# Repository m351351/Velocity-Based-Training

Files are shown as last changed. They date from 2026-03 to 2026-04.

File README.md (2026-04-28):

# Velocity-Based Training (VBT) - Device

[Suomeksi](README.md) | [In English](README_eng.md)

---

Tämä projekti on osa Oulun ammattikorkeakoulun tieto- ja viestintätekniikan toisen vuoden kevään elektroniikan sovellusprojekti-kurssia (2026). Projektin kesto on 7 viikkoa.

## Sisällysluettelo
* [Yleiskuvaus](#yleiskuvaus)
* [Laitteisto ja komponentit](#laitteisto-ja-komponentit)
* [Ohjelmisto ja teknologiat](#ohjelmisto-ja-teknologiat)
* [Toiminnallisuus](#toiminnallisuus)
* [Projektin hallinta](#projektin-hallinta)
* [Kuvat](#kuvat)

---

## Yleiskuvaus
Projektin tavoitteena on suunnitella ja toteuttaa Velocity-Based Training (VBT) -laite. Laite on tarkoitettu painonnostoon, jossa se mittaa levytangon liikettä ja antaa nostajalle reaaliaikaista palautetta noston nopeudesta ja räjähtävyydestä. 

Laite kiinnitetään tankoon, ja se lähettää kiihtyvyysdataa langattomasti Android-puhelimeen, joka visualisoi tiedon käyttäjälle graafisessa muodossa.

## Posteri
Juliste tarjoaa tiivistetyn yleiskuvan projektin tavoitteista, menetelmistä ja keskeisistä tuloksista.
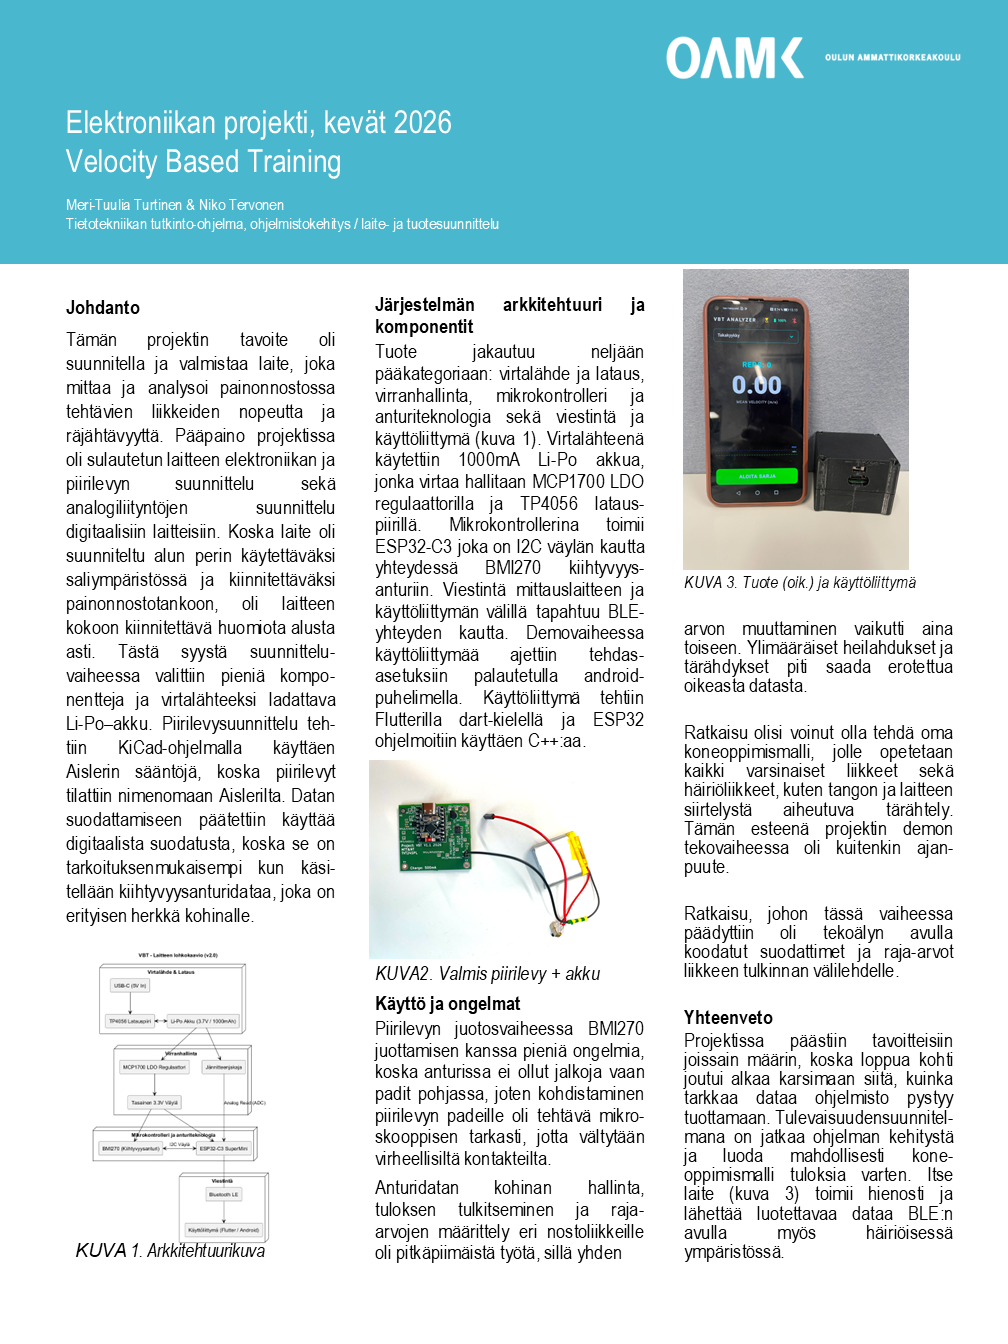
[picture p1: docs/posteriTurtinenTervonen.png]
Posteri


## Laitteisto ja komponentit
Piirilevy (PCB) on suunniteltu **KiCadilla** noudattaen **Aislerin** suunnittelusääntöjä: [aisler-support](https://github.com/AislerHQ/aisler-support). Laitteen sydämenä toimii ESP32-mikrokontrolleri.

### Komponenttilista:
* **Mikrokontrolleri:** ESP32 C3 Supermini
* **Anturi:** BMI270 (Kiihtyvyysanturi, I2C-väylä)
* **Virranhallinta:** * TP4056 (Latauspiiri)
    * MCP1700 (Regulaattori)

    * Vastukset: R1, R4 (4,7kΩ), R2, R3 (100kΩ), R5 (2,4kΩ), R6, R7 (10kΩ)
    * Kondensaattorit: C1, C2 (1µF), C3, C4 (100nF), C5, C6 (10µF)
* **Akku:** 3,7V litiumpolymeeriakku (Li-Po)
* **Älypuhelin** Huawei Honor View 20 (testikäyttöpuhelin)

## Ohjelmisto ja teknologiat
Projektissa on käytetty nykyaikaisia kehitystyökaluja ja kieliä:

* **Firmware:** ESP32 on ohjelmoitu C++-kielellä käyttäen **VS Codea**.
* **Mobiilisovellus:** Käyttöliittymä on toteutettu **Flutterilla** (Dart).
* **Viestintä:** Laitteen ja puhelimen välinen tiedonsiirto tapahtuu **Bluetooth Low Energy (BLE)** -yhteydellä.
* **Väylät:** ESP32 ja BMI270 kommunikoivat keskenään **I2C**-väylän kautta.

Puhelimeen asennettiin ohjelmisto yhdistämällä puhelin tietokoneeseen USB-kaapelilla ja ajamalla flutterohjelma suoraan puhelimeen. Käyttöjärjestelmän päivitykset ajetaan demovaiheessa suoraan testipuhelimeen.

Laitteen ohjelmistoon on koodattu virrankulutuksen optimointi.

## Toiminnallisuus
1. **Mittaus:** BMI270-anturi lukee tangon kiihtyvyyttä.
2. **Analyysi:** Data lähetetään BLE-yhteyden yli mobiilisovellukseen.
3. **Visualisointi:** Sovellus piirtää kiihtyvyydestä graafia ja laskee noston räjähtävyyden.
4. **Virransäästö:** Akunkestoa optimoidaan ohjelmallisesti asettamalla ESP32 lepotilaan (Deep Sleep), kun laitetta ei käytetä.
5. **Akun seuranta:** Käyttöliittymästä voi seurata reaaliajassa laitteen akun varaustilaa.

## Projektin hallinta
Projekti toteutettiin ketterillä menetelmillä ja se sisälsi seuraavat vaiheet:
* Vaatimusmäärittely ja projektisuunnitelman laatiminen.
* Sulautetun laitteen elektroniikan ja layout-suunnittelun.
* Ohjelmiston toteutuksen (Firmware & Mobile).
* Prototyypin testauksen ja käyttöönoton.

---

## Kuvat

### Piirilevyn valmistus
Piirilevy ja stensiili
Kuvassa piirilevy on upotettu pahvimuottiin, jonka päälle stensiili saadaan asetettua tiiviisti piirilevyä vasten pastan levitystä varten.

Component placing
Komponentit aseteltiin piirilevylle käsin.

BMI270
BMI270 komponentti on pieni ja sen padit ovat osan pohjassa, joten sen kanssa piti olla erityisen tarkka asetellessa sitä piirilevylle.

ready
Valmis ja uunitettu piirilevy sekä akku.

https://github.com/user-attachments/assets/68aac730-3347-450c-992c-2d826667e670

Video käyttöliittymästä

### Järjestelmäkaavio
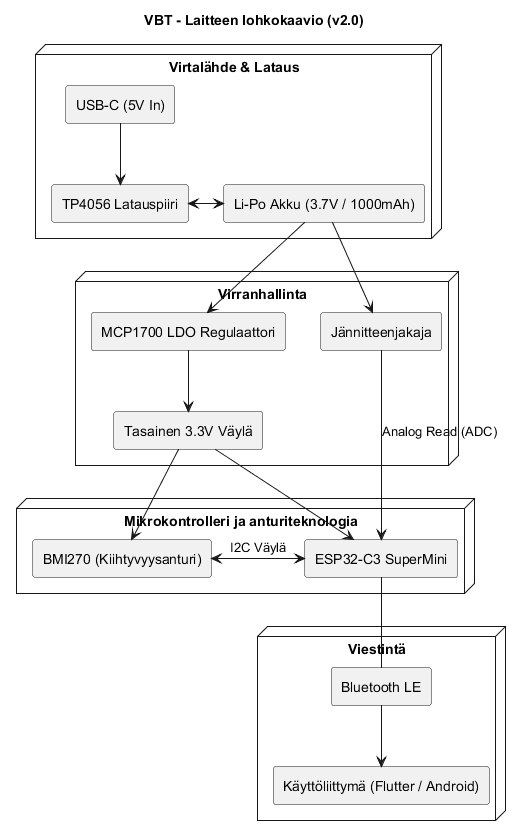
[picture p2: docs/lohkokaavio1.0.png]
Lohkokaavio
**

## Tulevaisuus
Tulevaisuudessa ohjelmistoa on tarkoitus kehittää niin, että eri nostoliikkeistä (takakyykky, maastaveto, penkkipunnerrus, tempaus, rinnalleveto ja rinnalleveto + työntö) on olemassa valmiit datasetit joiden perusteella ohjelma pystyy antamaan selkeän palautteen onko suoritus onnistunut ja mikä on nostajan kehityskaari. Tässä vaiheessa pääpaino on siinä, että laite toimii luotettavasti ja tehokkaasti, pystyy siirtämään ja näyttämään dataa reaaliaikaisesti, sekä seuraamaan akun varausta.

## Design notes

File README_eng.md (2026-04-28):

# Velocity-Based Training (VBT) - Device

[Suomeksi](README.md) | [In English](README_eng.md)

---

This project is part of the electronics application project course (Spring 2026) in the second year of Information and Communication Technology at Oulu University of Applied Sciences. The duration of the project is 7 weeks.

## Table of Contents
* [Overview](#overview)
* [Hardware and Components](#hardware-and-components)
* [Software and Technologies](#software-and-technologies)
* [Functionality](#functionality)
* [Project Management](#project-management)
* [Images](#images)

---

## Overview
The goal of the project is to design and implement a Velocity-Based Training (VBT) device. The device is intended for weightlifting, where it measures the movement of the barbell and provides the lifter with real-time feedback on the velocity and explosiveness of the lift.

The device is attached to the bar and sends acceleration data wirelessly to an Android phone, which visualizes the data for the user in a graphical format.

## Poster
The poster provides a condensed overview of the project's goals, methods, and key results.
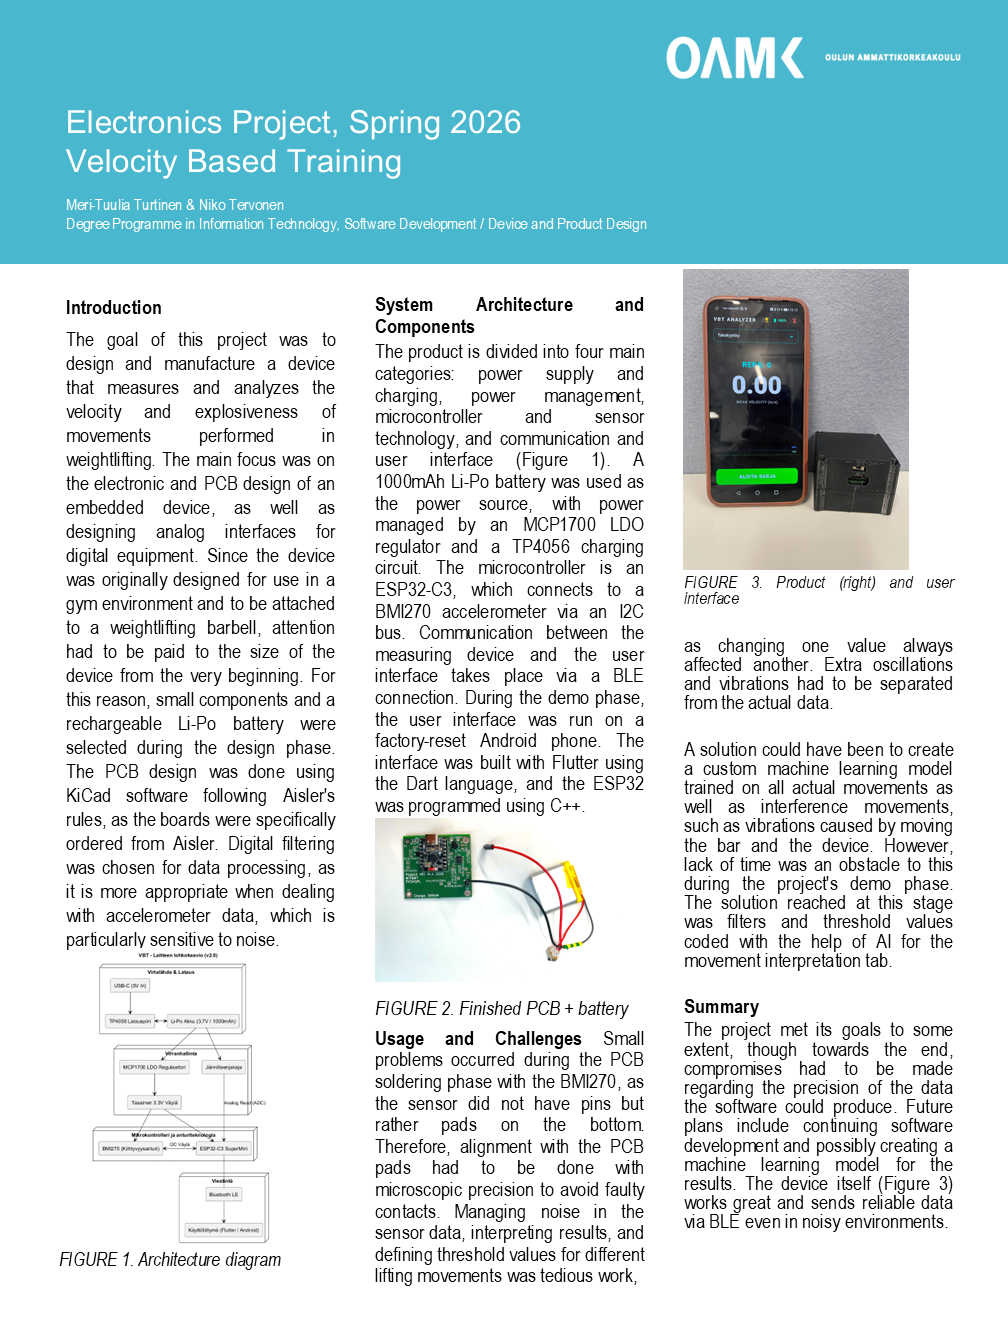
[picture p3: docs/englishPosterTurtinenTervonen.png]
Poster


## Hardware and Components
The Printed Circuit Board (PCB) was designed using **KiCad** following **Aisler's** design rules: [aisler-support](https://github.com/AislerHQ/aisler-support). An ESP32 microcontroller serves as the heart of the device.

### Component List:
* **Microcontroller:** ESP32 C3 Supermini
* **Sensor:** BMI270 (Accelerometer, I2C bus)
* **Power Management:**
    * TP4056 (Charging circuit)
    * MCP1700 (Regulator)
    * Resistors: R1, R4 (4.7kΩ), R2, R3 (100kΩ), R5 (2.4kΩ), R6, R7 (10kΩ)
    * Capacitors: C1, C2 (1µF), C3, C4 (100nF), C5, C6 (10µF)
* **Battery:** 3.7V Lithium Polymer (Li-Po) battery
* **Smartphone:** Huawei Honor View 20 (Testing device)

## Software and Technologies
Modern development tools and languages were used in the project:

* **Firmware:** The ESP32 is programmed in C++ using **VS Code**.
* **Mobile Application:** The user interface is implemented with **Flutter** (Dart).
* **Communication:** Data transfer between the device and the phone occurs via **Bluetooth Low Energy (BLE)**.
* **Buses:** The ESP32 and BMI270 communicate with each other via the **I2C** bus.

The software was installed on the phone by connecting it to a computer via USB and running the Flutter program directly on the device. During the demo phase, operating system updates are deployed directly to the test phone.

Power consumption optimization has been coded into the device's firmware.

## Functionality
1. **Measurement:** The BMI270 sensor reads the acceleration of the barbell.
2. **Analysis:** Data is sent over a BLE connection to the mobile application.
3. **Visualization:** The app draws a graph of the acceleration and calculates the explosiveness of the lift.
4. **Power Saving:** Battery life is optimized programmatically by putting the ESP32 into **Deep Sleep** when the device is not in use.
5. **Battery Monitoring:** The real-time battery status of the device can be monitored from the UI.

## Project Management
The project was implemented using agile methods and included the following phases:
* Requirement specification and drafting the project plan.
* Embedded device electronics and layout design.
* Software implementation (Firmware & Mobile).
* Prototype testing and commissioning.

---

## Images

### PCB Manufacturing
PCB and stencil
In the image, the PCB is embedded in a cardboard mold, over which the stencil is tightly placed against the board for solder paste application.

Component placing
Components were placed on the circuit board by hand.

BMI270
The BMI270 component is small and its pads are on the bottom, so extra precision was required when placing it on the PCB.

ready
The finished and reflowed PCB and the battery.

https://github.com/user-attachments/assets/65e12cbe-5f19-4288-899f-408d515f880d

### System Diagram
*Block Diagram*

## Future
In the future, the software is intended to be developed so that ready-made datasets exist for different lifts (back squat, deadlift, bench press, snatch, clean, and clean & jerk). Based on these, the program can provide clear feedback on whether the performance was successful and track the lifter's progress curve. At this stage, the main focus is on ensuring the device operates reliably and efficiently, can transfer and display data in real-time, and monitor battery levels.

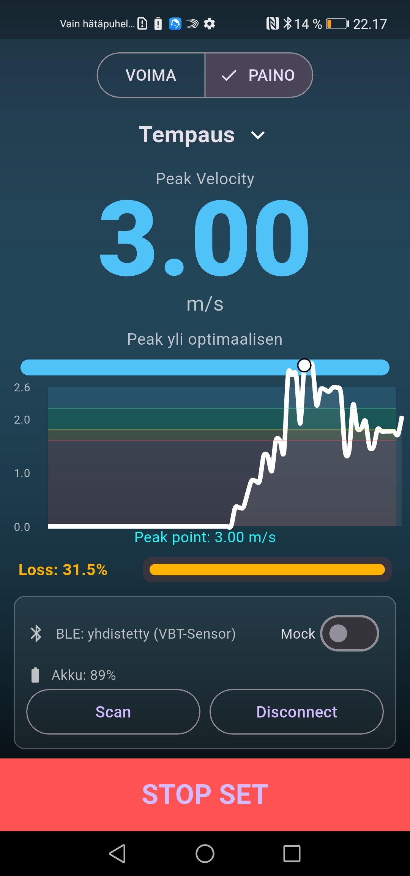
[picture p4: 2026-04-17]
docs/flutterApplication.jpg

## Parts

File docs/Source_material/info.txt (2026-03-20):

lisätietoja lähteistä
https://www.kaggle.com/datasets/krishujeniya/fitness-tracker-accelerometer-and-gyroscope-data
otettu dataa käyttöliittymän testausta varten

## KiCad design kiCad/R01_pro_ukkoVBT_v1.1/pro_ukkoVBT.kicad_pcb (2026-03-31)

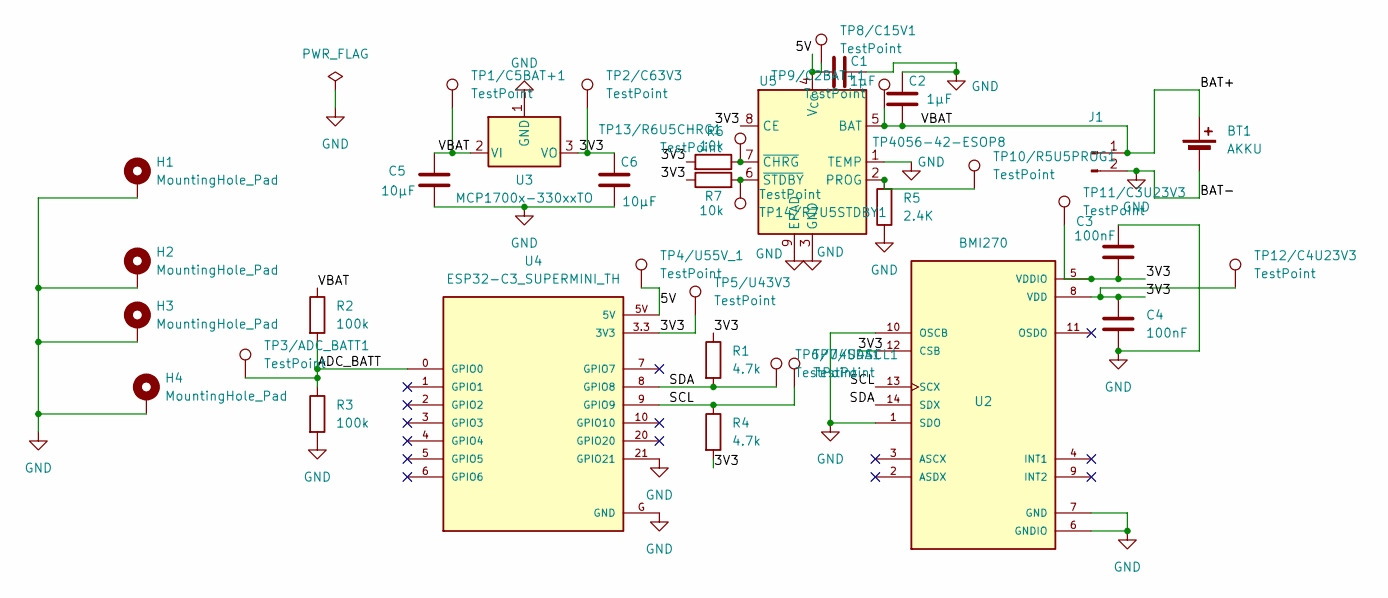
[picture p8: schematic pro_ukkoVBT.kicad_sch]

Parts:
BT1: AKKU
C1, C2: 1µF; C_0603_1608Metric
C3, C4: 100nF; C_0603_1608Metric
C5, C6: 10µF; C_0603_1608Metric
H1, H2, H3, H4: MountingHole_Pad; MountingHole_2.2mm_M2_Pad
J1: Conn_01x02_Pin; PinHeader_1x02_P2.54mm_Vertical
R1, R4: 4.7k; R_0603_1608Metric
R2, R3: 100k; R_0603_1608Metric
R5: 2.4K; R_0603_1608Metric
R6, R7: 10k; R_0603_1608Metric
TP1/C5BAT+1, TP2/C63V3, TP3/ADC_BATT1, TP4/U55V_1, TP5/U43V3, TP6/U4SDA1, TP7/U4SCL1, TP8/C15V1, TP9/C2BAT+1, TP10/R5U5PROG1, TP11/C3U23V3, TP12/C4U23V3, TP13/R6U5CHRG1, TP14/R7U5STDBY1: TestPoint; TestPoint_Pad_1.5x1.5mm
U2: BMI270; XDCR_BMI270
U3: MCP1700x-330xxTO; TO-92_Inline
U4: ESP32-C3_SUPERMINI_TH; MODULE_ESP32-C3_SUPERMINI_TH
U5: TP4056-42-ESOP8; SOIC-8-1EP_3.9x4.9mm_P1.27mm_EP2.41x3.3mm_ThermalVias

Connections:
/3V3: C3.2, C4.1, C6.1, R1.1, R4.2, R6.2, R7.1, TP2/C63V3.1, TP5/U43V3.1, TP11/C3U23V3.1, TP12/C4U23V3.1, U2.5 (VDDIO), U2.8 (VDD), U2.12 (CSB), U3.3 (VO), U4.3.3 (3V3), U5.8 (CE)
/5V: C1.1, TP4/U55V_1.1, TP8/C15V1.1, U4.5V, U5.4 (V_{CC})
/ADC_BATT: R2.2, R3.1, TP3/ADC_BATT1.1, U4.0 (GPIO0)
/BAT+: BT1.1 (+), C2.1, C5.1, J1.1, R2.1, TP1/C5BAT+1.1, TP9/C2BAT+1.1, U3.2 (VI), U5.5 (BAT)
/SCL: R4.1, TP7/U4SCL1.1, U2.13 (SCX), U4.9 (GPIO9)
/SDA: R1.2, TP6/U4SDA1.1, U2.14 (SDX), U4.8 (GPIO8)
GND: BT1.2 (-), C1.2, C2.2, C3.1, C4.2, C5.2, C6.2, H1.1, H2.1, H3.1, H4.1, J1.2, R3.2, R5.1, U2.1 (SDO), U2.6 (GNDIO), U2.7 (GND), U2.10 (OSCB), U3.1 (GND), U4.21 (GPIO21), U4.G (GND), U5.1 (TEMP), U5.3 (GND), U5.9 (EPAD)
unnamed: R5.2, TP10/R5U5PROG1.1, U5.2 (PROG)
unnamed: R6.1, TP13/R6U5CHRG1.1, U5.7 (~CHRG)
unnamed: R7.2, TP14/R7U5STDBY1.1, U5.6 (~STDBY)

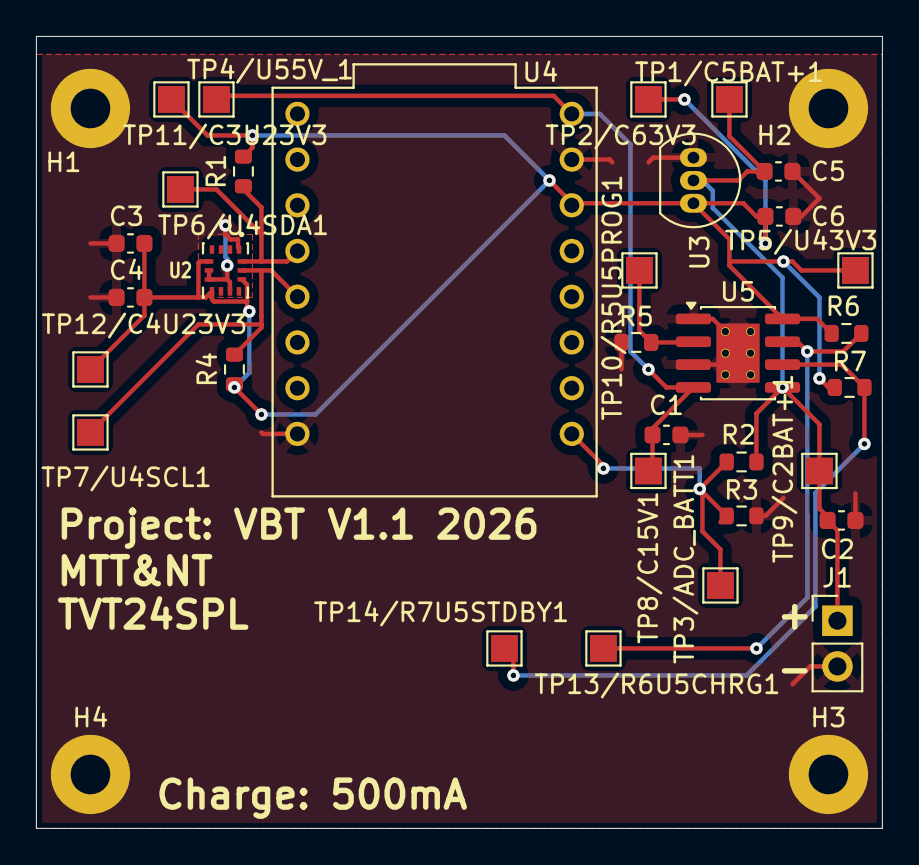
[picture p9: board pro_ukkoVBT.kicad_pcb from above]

Board: 2 copper layers, 47.0 x 44.0 mm, 36 parts (0 on the bottom side), 10 nets.

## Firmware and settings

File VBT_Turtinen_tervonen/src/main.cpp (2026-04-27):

#include <Arduino.h>
#include <Wire.h> // I2C-VÄYLÄKIRJASTO
#include <math.h>
#include <BLEUtils.h>
#include "Arduino_BMI270_BMM150.h" // Kiihtyvyysanturin ajurikirjasto
#include "Battery.h" // Akun mittausmoduuli
#include "BLEHandler.h" // BLE-yhteysmoduuli
#include "Motion.h" // Liiketunnistusmoduuli
#include "OTA.h" // Langattoman päivityksen "Over the air" moduuli

// I2C-pinnit (ESP32-C3 Superminille)
// SDA = Serial Data, SCL = Serial Clock
#define I2C_SDA 8
#define I2C_SCL 9

// Tämä hoitaa BMI270:n I2C-kommunikoinnin
BoschSensorClass imu(Wire);

void setup() {
  Serial.begin(115200);
  delay(300);
// ADC-konfiguraatio akun mittausta varten
  Wire.begin(I2C_SDA, I2C_SCL);
  analogReadResolution(12);
// Alustetaan IMU ja BLE
  if (!imu.begin()) {
    Serial.println("BMI270 ei vastaa! Jatketaan BLE:llä.");
  }

  setupBLE(); // Alustetaan BLE
  setupMotion(); // Alustetaan IMU-kalibrointi ja laskenta

  updateBattery(false); // Luetaan akun tila heti käynnistyksen yhteydessä

}


void loop() {
    /* JÄTETÄÄN OVER THE AIR- PÄIVITYS KÄYTÖSTÄ TOISTAISEKSI, JATKOKEHITYSTÄ VARTEN KUITENKIN JÄTÄN TÄHÄN */
   // handleOTA();
  
   // LEPOTILA: Puhelin ei ole yhdistettynä
    if (!bleConnected) {
    
    handleBattery(); // Päivitetään akun tila, jotta puhelin saa ajan tasalla olevan prosenttilukeman heti yhdistettäessä
    delay(200);      // Tämä 200ms antaa ESP32:n nukkua taustalla!
    return;          
  }
  
  // AKTIIVITILA: Puhelin yhdistettynä, mittaillaan ja lähetetään dataa
  handleBattery(); // Akun seuranta
  handleMotion(); // IMU-lukeminen, nopeuden laskenta, toistojen tunnistus
  sendVelocityNotify(velocity); // Lähetetään nopeus puhelimeen

}

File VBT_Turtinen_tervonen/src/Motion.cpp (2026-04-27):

#include "Motion.h"
#include <Wire.h>
#include "Exercise.h"
#include "BLEHandler.h"

extern BoschSensorClass imu;
extern ExerciseType currentExercise;

// Nopeusmuuttujat
float velocity = 0.0f; // Tämä lähetetään puhelimeen (vain positiivinen)
static float internalVelocity = 0.0f; // Sisäinen fysiikan nopeus


// Kalibrointimuuttujat
// Gravitaatiokiihtyvyden suunta kalibrointihetkellä
float cal_ax = 0, cal_ay = 0, cal_az = 0;
// Gravitaativektorin pituus kalibrointihetkellä (normaalisti noin 1.0 G)
float cal_mag = 1.0f;

// Ajastimet IMU-lukemiselle ja nopeuden laskulle
unsigned long lastVelMs = 0; // Integroinnin viiteaika (dt-laskentaa varten)
unsigned long lastImuMs = 0; // IMU-lukemisen ajankohta
const uint32_t IMU_INTERVAL_MS = 20; // 50 Hz <- SÄÄDÄ TARVITTAESSA

// Lepotilan tunnistuksen ajastimet (Signaalin rauhoitus)
static unsigned long restStableMs = 0; // Milloin laite alkoi olla paikallaan (aika nollaantuu liikkeessä)
static unsigned long repBelowMs = 0; // Milloin nopeus viimeksi laski alle rajan (toiston loppu)

// Toistojen seuranta
bool inRep = false; // Onko toisto käynnissä? 
static float repMaxVel = 0.0f; // Toiston korkein mitattu nopeus
static float repSumVel = 0.0f; // Kaikkien nopeuksien summa toiston aikana (keskiarvoa varten)
static int repPoints = 0; // Näytteiden lukumäärä toistojen aikana

void setupMotion() {
    calibrateMotion(); // Mitataan laitteen lepotilan asento
    lastVelMs = millis(); // Nopeuslaskenta alkaa
    lastImuMs = millis(); // IMU-lukeminen alkaa
    Serial.println("Aika_ms,KokonaisG,DynaaminenG,SisainenNopeus,BLE_Nopeus"); 
}

void calibrateMotion() {
    float sum_x = 0, sum_y = 0, sum_z = 0;
    int samples = 100; // 100 näytettä kalibrointiin = noin 1 sekunti paikallaan!
    Serial.println("Kalibroidaan... Pida laite paikallaan.");
    
    for (int i = 0; i < samples; i++) {
        if (imu.accelerationAvailable()) {
            float ax, ay, az;
            imu.readAcceleration(ax, ay, az); // Luetaan kiihtyvyys (yksikkö = G)
            sum_x += ax;
            sum_y += ay;
            sum_z += az;
        }
        delay(10);
    }

    // Lasketaan kalibrointiarvojen keskiarvo
    cal_ax = sum_x / samples;
    cal_ay = sum_y / samples;
    cal_az = sum_z / samples;
    // Gravitaatiovektorin pituus kalibrointihetkellä
    cal_mag = sqrtf(cal_ax*cal_ax + cal_ay*cal_ay + cal_az*cal_az);
}

// Pääsilmukka, joka lukee IMU:ta, laskee nopeuden ja tunnistaa toistot
// Pääsilmukka, joka lukee IMU:ta, laskee nopeuden ja tunnistaa toistot
void handleMotion() {
    // Jos BLE ei ole yhdistetty, nollataan tilanne ja poistutaan
    if (!bleConnected) {
        lastVelMs = millis();
        lastImuMs = millis();
        internalVelocity = 0.0f;
        velocity = 0.0f;
        restStableMs = 0;
        inRep = false;
        return; 
    }

    unsigned long now = millis();
    ExerciseParams params = getExerciseParams(currentExercise);

    // IMU + velocity @ 50 Hz
    if (now - lastImuMs >= IMU_INTERVAL_MS) {
        lastImuMs += IMU_INTERVAL_MS;
        
        if (imu.accelerationAvailable()) { // Uutta dataa saatavilla?
            float ax, ay, az;
            imu.readAcceleration(ax, ay, az); // Luetaan akseleraatiolukemat

            float dt = 0.02f;
            lastVelMs = now;

            // Dynaamisen kiihtyvyyden laskenta kalibroidun gravitaatiovektorin avulla
            float dot = (ax * cal_ax + ay * cal_ay + az * cal_az) / cal_mag;
            float dynamicAccG = dot - cal_mag;

            //LEPOTILAN TUNNISTUS JA FYSIIKKA
            if (fabsf(dynamicAccG) < 0.04f && fabsf(internalVelocity) < 0.08f) {
                if (restStableMs == 0) restStableMs = now; // Lepotilan alkamisaika
                
                if (now - restStableMs > 200) { 
                    cal_ax = cal_ax * 0.90f + ax * 0.10f;
                    cal_ay = cal_ay * 0.90f + ay * 0.10f;
                    cal_az = cal_az * 0.90f + az * 0.10f;
                    cal_mag = sqrtf(cal_ax*cal_ax + cal_ay*cal_ay + cal_az*cal_az);
                    // Lepotilassa nopeus nollataan = estää driftin kertymisen
                    internalVelocity = 0.0f;
                    velocity = 0.0f;
                }
            } else {
                restStableMs = 0; // Liike alkoi -> Nollataan lepotilan ajastin
                
                // Nopeuslaskenta: Integroi dynaaminen kiihtyvyys vain jos se ylittää aloituskynnyksen
                if (fabsf(dynamicAccG) > 0.04f) {
                    internalVelocity += dynamicAccG * 9.81f * dt;
                }
                
                // Nopeuden hallinta: Pehmennetään nopeuden laskua hidastusvaiheessa ja pysähdyksissä
                if (internalVelocity > 0.0f) {
                    if (dynamicAccG < -0.04f) {
                        // Hidastuvaihe: Painovoima iskee vastaan. Pehmennetään käyrää hieman.
                        internalVelocity *= 0.95f; 
                    } else if (fabsf(dynamicAccG) <= 0.04f) {
                        // Pysähdys = haamunopeus pois
                        internalVelocity *= 0.80f; 
                    }
                    
                } else {
                    // Tapetaan mahdolliset miinukselle valuvat nopeudet nopeasti
                    internalVelocity *= 0.80f;
                }
            }

            // Rajoitetaan sisäinen nopeus
            internalVelocity = constrain(internalVelocity, -0.5f, 10.0f);

            // Näyttönopeus on aina posiivinen ja nollataan jos sisäinen nopeus liian pieni
            if (internalVelocity > 0.0f) {
                velocity = internalVelocity;
            } else {
                velocity = 0.0f;
            }

            // 2. TOISTOJEN NOPEUSRAJOITUS JA TUNNISTUS. Tilakone inRep = true/false
            if (velocity > 0.05f) {
                // Toisto on käynnissä
                if (!inRep) {
                    inRep = true;
                    repMaxVel = 0.0f;
                    repSumVel = 0.0f;
                    repPoints = 0;
                    Serial.println("\nTOISTO ALKOI");
                }

                // Päivitetään toiston tilastot
                if (velocity > repMaxVel) repMaxVel = velocity; // Huippunopeus
                repSumVel += velocity; // Nopeuksien summa keskiarvoa varten
                repPoints++; // Näytteiden lukumäärä
                
                repBelowMs = 0; // Nollataan laskuri jotta toisto ei pääty vahingossa kesken
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

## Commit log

2026-03-09 Initial project setup and documentation
    Added gitignore
    Added project plan and work hours template
    Added meeting agenda template
    [Work_hours.xlsx]
2026-03-20 Lisätty kytkentäkaaviohakemisto ja dokumentaatiota
    [01_Data_Processed_bench.csv, piirilevysuunnittelu.kicad_pcb, piirilevysuunnittelu.kicad_sch]
2026-03-24 flutter: add mock live velocity chart
2026-03-31 added kicad pcd design and other related files
    [piirilevysuunnittelu.kicad_pcb, piirilevysuunnittelu.kicad_sch, pro_ukkoVBT.kicad_pcb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]
2026-03-31 Siivottu kansiorakennetta ja poistettu turhat tiedostot
    [01_Data_Processed_bench.csv]
2026-04-15 functionin PCB is being made and sending data succesfully to UI
2026-04-16 deleted unfunctioning flutter code and modified cpp for ESP (battery charge state)
2026-04-27 Add: Fully commented ESP32 source codes. Refactor: physics engine, fix integration drift and optimized BLE/battery loop.
    [BLEHandler.cpp, Battery.cpp, Motion.cpp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]
